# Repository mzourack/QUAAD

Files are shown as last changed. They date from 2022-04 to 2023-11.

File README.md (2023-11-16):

# QUAAD
quad 4-step Eurorack CV sequencer

current version:

PCB     V1.1

Panel   V1.1

**Features**

Demo: https://www.youtube.com/watch?v=YCnnyX1JADY

This module is basically 4 independent 4-step sequencers. Each of them features a CV output (0-5V), a clock divider (1-2-3-4-5-7-8-12-16-32 divisions) and a pattern setting.
There are 6 patterns available, each one unique, as there are no repeating 4-step sequences between the looped patterns. Patterns can be changed per-sequence via a dedicated knob or via CV, aswell as globally using the MSTR PTRN knob, which basically adds a CV offset to each of the pattern CV inputs. The full range of patterns can be accesed via the pot corresponding to pattern changes of individual sequencers, the MSTR PTRN knob or via 0-5V CV. The patterns are looped, so that when, for example, you are on the last of the 6 patterns and add some positive CV offset, you will go back to the first one and then further on...
The patterns are determined by this variable in the Arduino code:

    int patterns[] = {1, 2, 3, 4,
                      1, 2, 4, 3,
                      2, 4, 1, 3,
                      3, 4, 2, 1,
                      4, 2, 3, 1,
                      4, 3, 2, 1};

The sequencer can be reset via a gate or manually using a button.
With nothing patched into the clock input, the module is clocked internally, the tempo can be set via a potentiometer. The clock output outputs this internal clock when no external clock input is patched in, otherwise, the incoming clock signal is buffered through this output.

The module is 22HP, no 5V source required from the rack.



**Hardware**



Not much to say here, the build is fairly straight forward. It features SMD components, the passives are 0603. 

**Firmware**

Complete step-by-step flashing guide available in the pdf file in this repository.

The Atmega328P is running on Arduino code - this means an Arduino bootloader needs to be flashed before the .ino code. To flash it, you can use an arduino (uno or nano for example) and a couple of jumper wires. I recommend to flash the module disconnected from the rack - the 5V needed to run the chip can be provided via the ICSP header. I used a USBASP from aliexpress, it works great but was quite hard to get working, so I cannot recommend it. If you do go down the USBASP route, note that you need to place a jumper on the programmer that slows down the data transfer frequency - a factory fresh atmega328p won't be able to accept the bootloader at USBASP default speed.

Here's the pinout of the ICSP header used for flashing the chip:



Finally, TX and RX pins are available on the back of the module. These can theoretically be used to debug the module, and could prove useful for testing new firmware. However, clock div out C and D have to be disabled in such case.

**License**

Shield: [][cc-by]

This work is licensed under a
[Creative Commons Attribution 4.0 International License][cc-by].

[][cc-by]

[cc-by]: http://creativecommons.org/licenses/by/4.0/
[cc-by-image]: https://i.creativecommons.org/l/by/4.0/88x31.png
[cc-by-shield]: https://img.shields.io/badge/License-CC%20BY%204.0-lightgrey.svg

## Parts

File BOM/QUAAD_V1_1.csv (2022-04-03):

Id | Designator | Package | Quantity | Designation | Supplier and ref
1 | Ref** | logo_18 | 1 | Val**
2 | RV16,RV24,RV1,RV2,RV3,RV5,RV6,RV7,RV10,RV11,RV12,RV13,RV14,RV15,RV17,RV18,RV19,RV20,RV21,RV22,RV23,RV26,RV4,RV25,RV9,RV8 | Potentiometer_Alpha_RD901F-40-00D_Single_Vertical | 26 | B100K
3 | D20,D19,D10,D9,D4,D3,D2,D1 | D_SOD-123 | 8 | BAT42
4 | C6,C7,C8,C9,C10,C11,C12,C15,C16,C17,C18,C19,C25,C26,C27,C28,C29,C30,C31,C14 | C_0603_1608Metric | 20 | 100n
5 | R62,R61,R3,R4,R11,R12,R17,R18,R21,R22,R23,R24,R35,R36,R39,R40,R44,R45,R48,R49,R52,R53,R57,R58,R60 | R_0603_1608Metric | 25 | 1K
6 | J17 | PinHeader_1x02_P2.54mm_Vertical | 1 | Conn_01x02
7 | D35,D34,D33,D32,D31,D30,D29,D28,D27,D25,D24,D22,D21,D18,D17,D16,D15,D14,D13,D12,D11,D8,D7,D6,D5 | CENTERED_FLAT_LED | 25 | LED
8 | D26,D23 | D_SOD-123 | 2 | 1N4148W
9 | C1,C2,C3,C4,C5 | C_0603_1608Metric | 5 | 470n
10 | C13,C20 | CP_Elec_5x5.8 | 2 | 22u
11 | C21,C22 | C_0603_1608Metric | 2 | 18p
12 | C23,C24 | C_0603_1608Metric | 2 | 1u
13 | CON1 | IDC-Header_2x05_P2.54mm_Vertical | 1 | POWER
14 | D36,D37 | D_SOD-123F | 2 | SM4001
15 | J1,J2,J3,J4,J5,J7,J8,J9,J10,J11,J12,J13,J14,J15,J6 | Jack_3.5mm_QingPu_WQP-PJ398SM_Vertical | 15 | THONKICONN
16 | J16 | PinHeader_2x03_P2.54mm_Vertical | 1 | ICSP
17 | Q1,Q2 | SOT-23 | 2 | MMBT3904
18 | R1,R2,R7,R8,R15,R16,R25,R26,R29,R30,R37,R38 | R_0603_1608Metric | 12 | 68K
19 | R5,R6,R9,R10,R13,R14,R27,R28,R31,R32,R33,R34,R51,R59 | R_0603_1608Metric | 14 | 10K
20 | R19,R20,R41,R42,R43 | R_0603_1608Metric | 5 | 33K
21 | R46,R50 | R_0603_1608Metric | 2 | 100K
22 | R47 | R_0603_1608Metric | 1 | 220K
23 | R54,R55,R56 | R_0603_1608Metric | 3 | 1M
24 | U3,U4,U8,U9 | SOP-16_4.55x10.3mm_P1.27mm | 4 | CD4052B
25 | U12 | TQFP-32_7x7mm_P0.8mm | 1 | ATmega328P-AU
26 | Y1 | Crystal_SMD_HC49-SD | 1 | 16MHz
27 | SW1 | SW_PUSH_6mm | 1 | SW_DIP_x01
28 | U11 | SOT-223-3_TabPin2 | 1 | LM1117-5.0
29 | U1,U2,U5,U6,U10 | SOIC-14_3.9x8.7mm_P1.27mm | 5 | TL074
30 | U7 | SOIC-8_3.9x4.9mm_P1.27mm | 1 | TL072

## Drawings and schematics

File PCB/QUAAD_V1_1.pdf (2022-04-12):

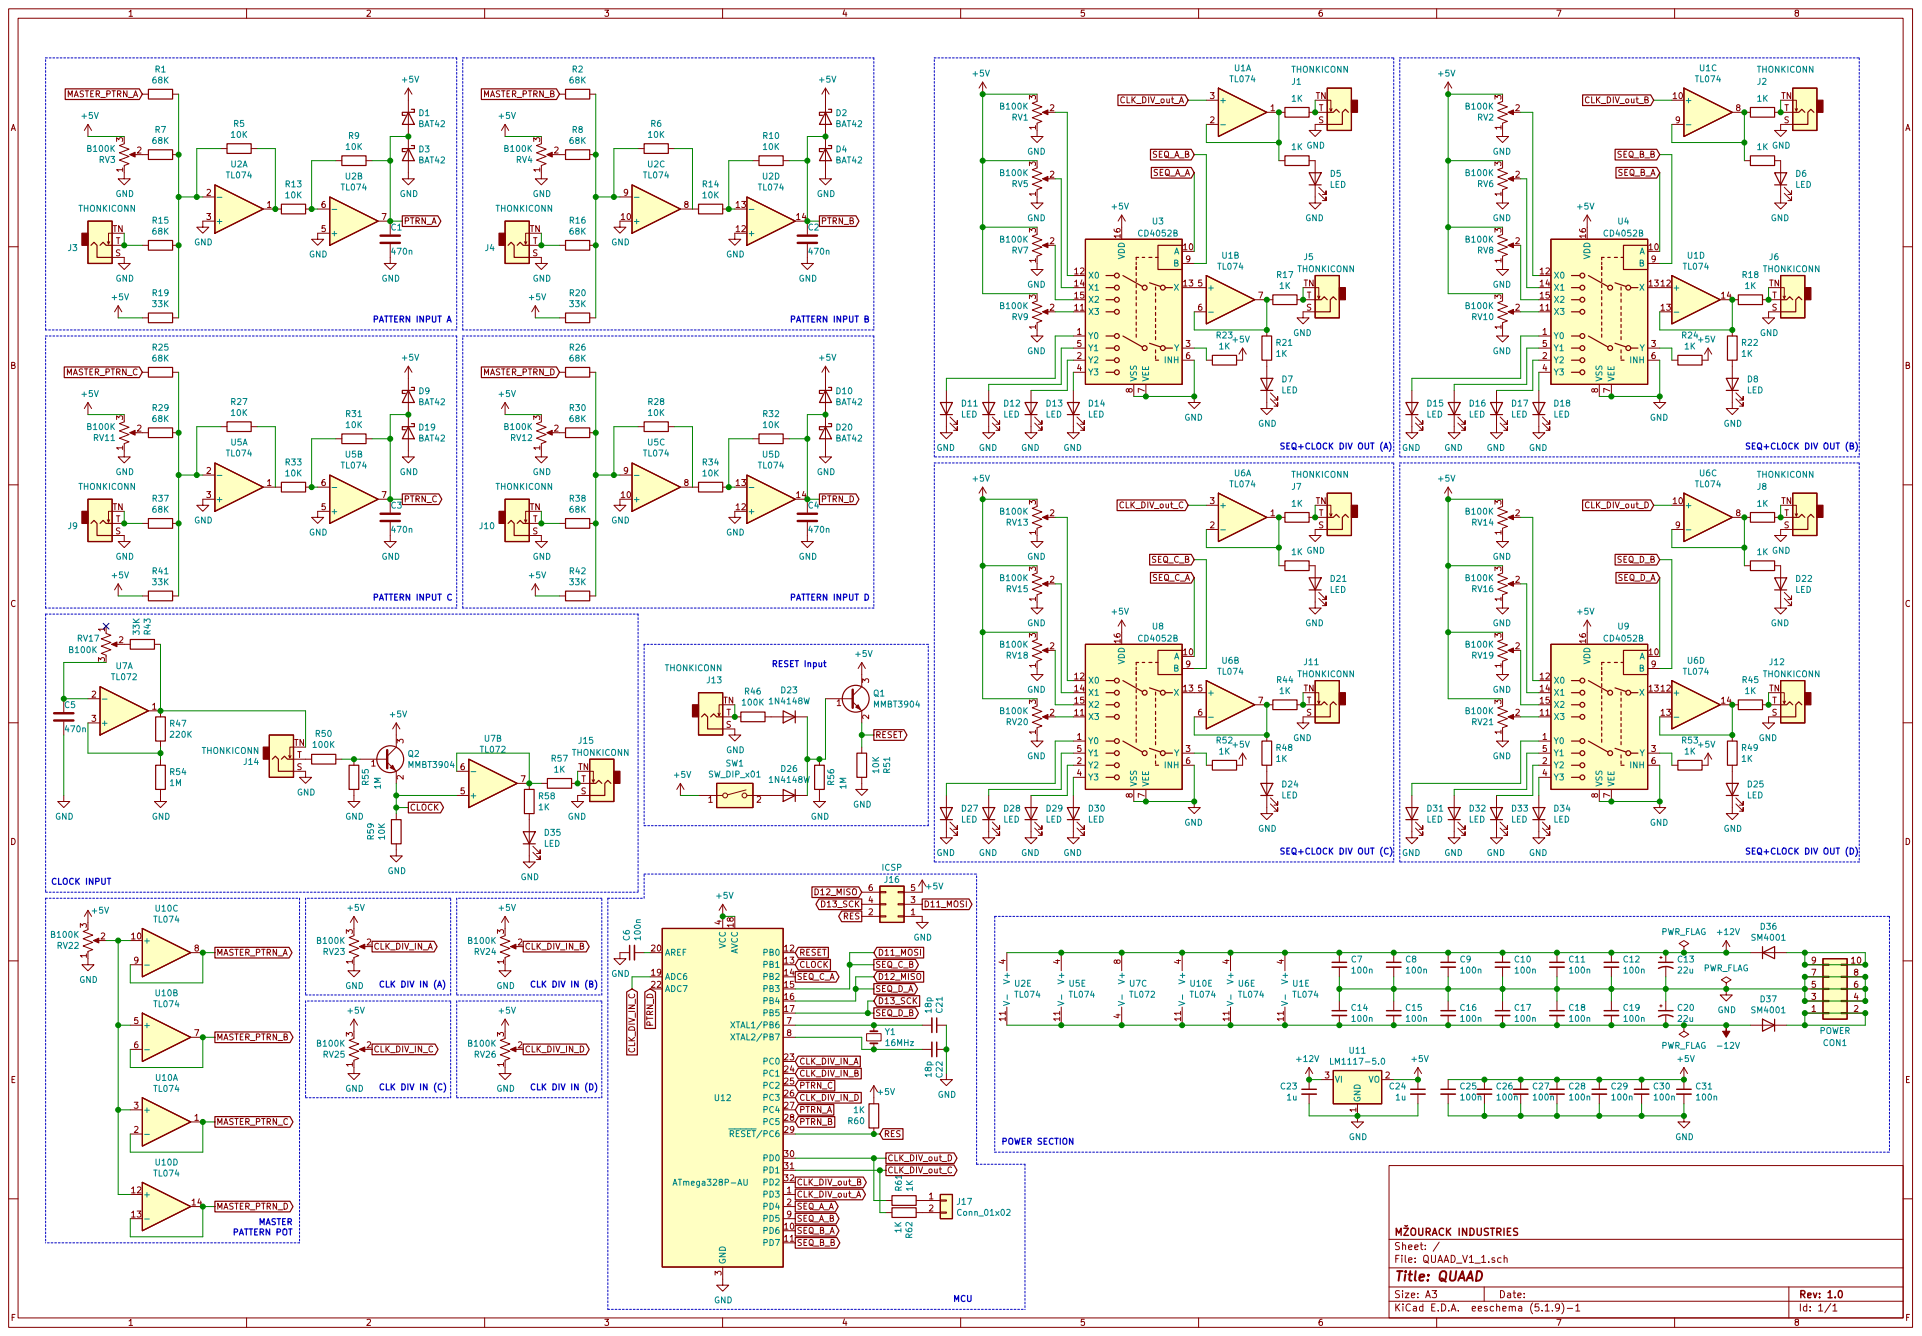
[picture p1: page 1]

SEQ+CLOCK DIV OUT (C)

2 | - 9 U10C 10 | 2 | 2 CLK DIV IN (B)

GND +5V 2 CLK DIV IN (C) | GND GND GND +5V 2 CLK DIV IN (D)

File: QUAAD_V1_1.sch Sheet: / MOURACK INDUSTRIES

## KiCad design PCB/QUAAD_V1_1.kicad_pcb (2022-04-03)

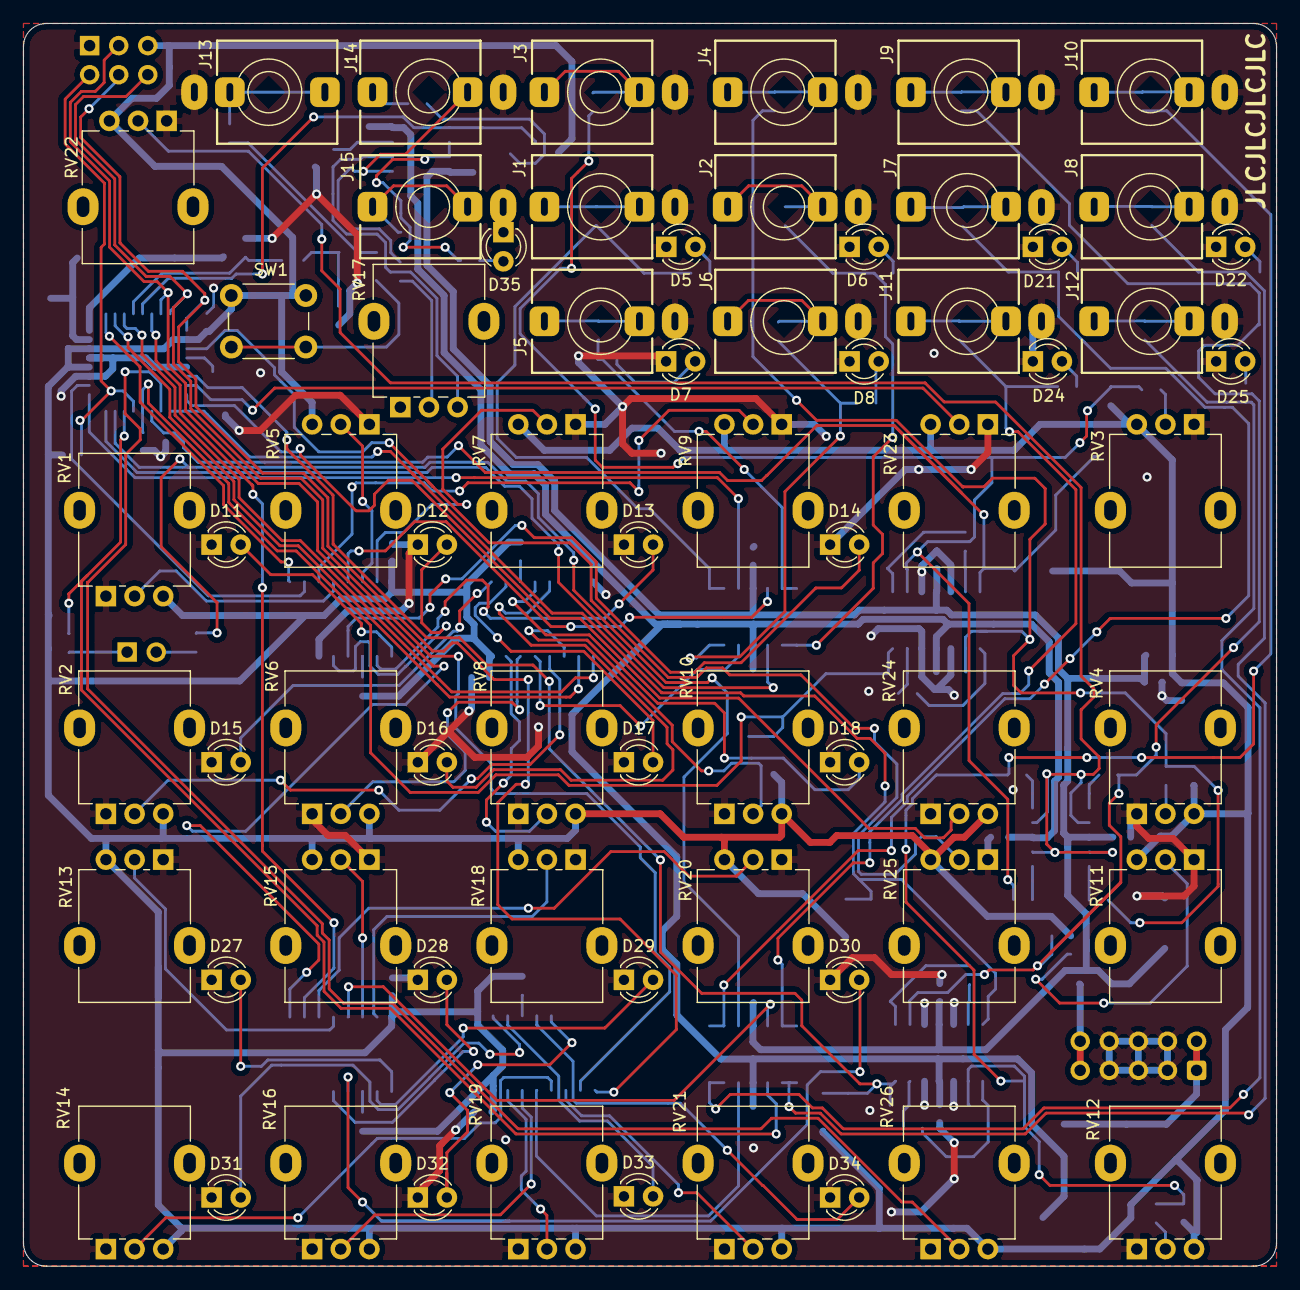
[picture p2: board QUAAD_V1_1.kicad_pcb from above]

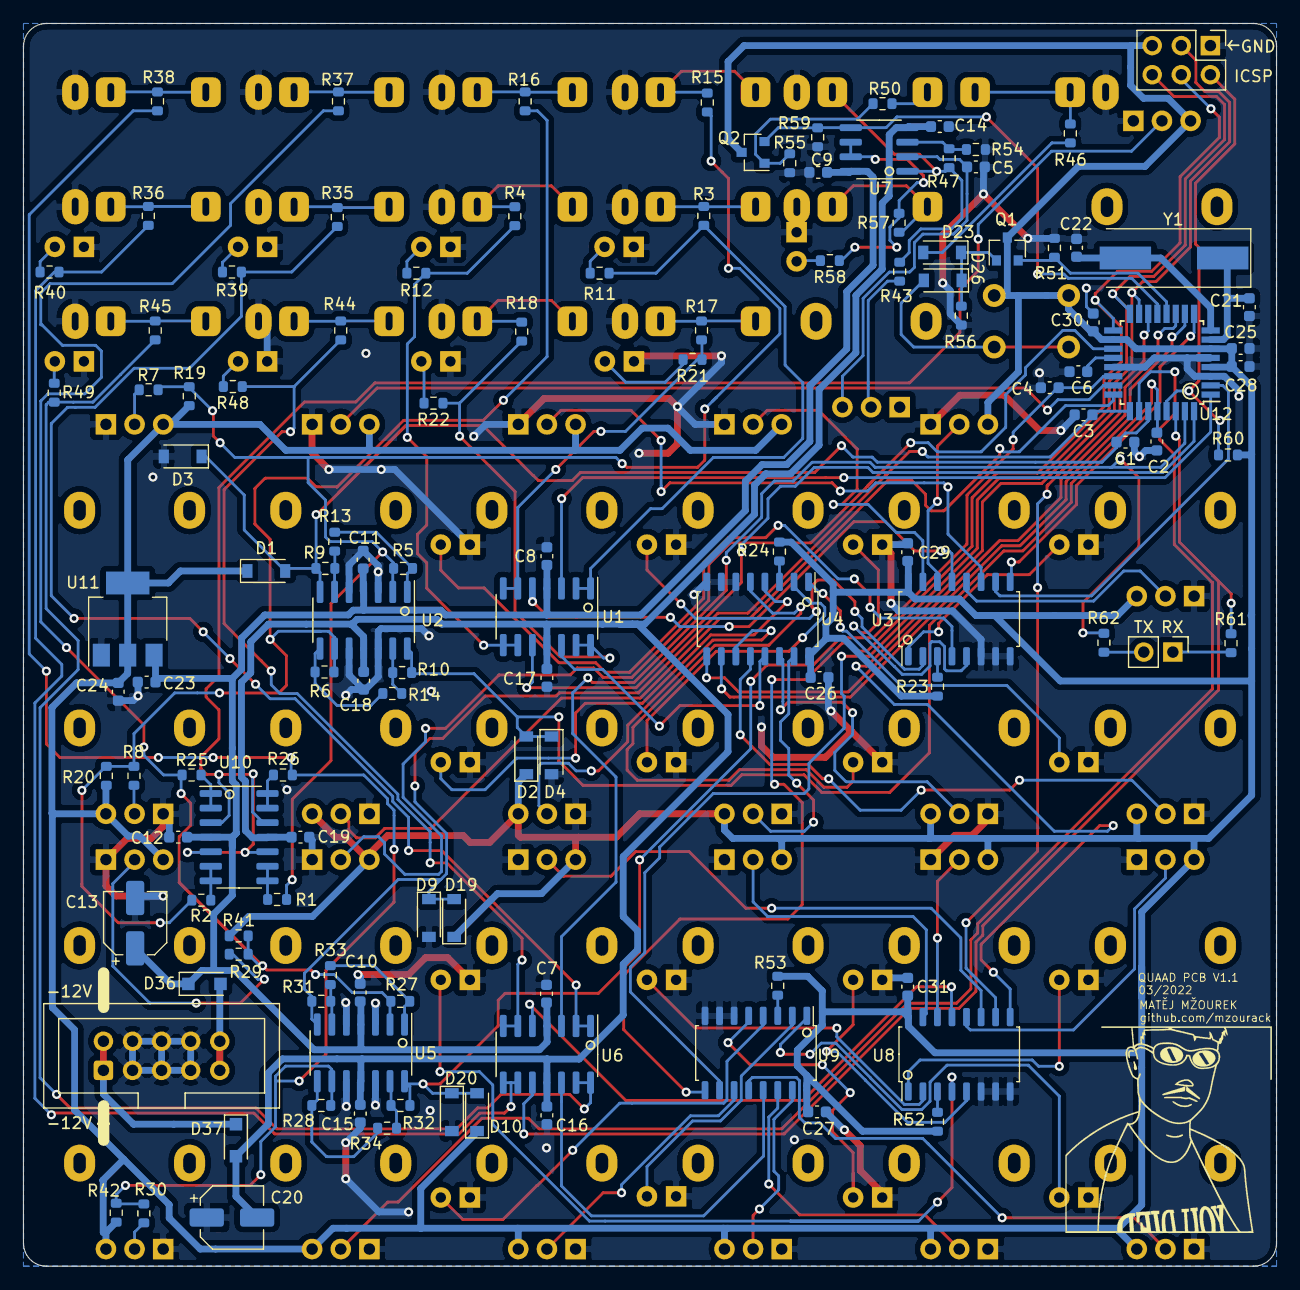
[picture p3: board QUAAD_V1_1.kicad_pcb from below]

Board: 2 copper layers, 109.4 x 108.5 mm, 191 parts (123 on the bottom side), 136 nets.

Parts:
C1, C2, C3, C4, C5: 470n; C_0603_1608Metric
C6, C7, C8, C9, C10, C11, C12, C14, C15, C16, C17, C18, C19, C25, C26, C27, C28, C29, C30, C31: 100n; C_0603_1608Metric
C13, C20: 22u; CP_Elec_5x5.8
C21, C22: 18p; C_0603_1608Metric
C23, C24: 1u; C_0603_1608Metric
CON1: POWER; IDC-Header_2x05_P2.54mm_Vertical
D1, D2, D3, D4, D9, D10, D19, D20: BAT42; D_SOD-123
D5, D6, D7, D8, D11, D12, D13, D14, D15, D16, D17, D18, D21, D22, D24, D25, D27, D28, D29, D30, D31, D32, D33, D34, D35: LED; CENTERED_FLAT_LED
D23, D26: 1N4148W; D_SOD-123
D36, D37: SM4001; D_SOD-123F
J1, J2, J3, J4, J5, J6, J7, J8, J9, J10, J11, J12, J13, J14, J15: THONKICONN; Jack_3.5mm_QingPu_WQP-PJ398SM_Vertical
J16: ICSP; PinHeader_2x03_P2.54mm_Vertical
J17: Conn_01x02; PinHeader_1x02_P2.54mm_Vertical
Q1, Q2: MMBT3904; SOT-23
R1, R2, R7, R8, R15, R16, R25, R26, R29, R30, R37, R38: 68K; R_0603_1608Metric
R3, R4, R11, R12, R17, R18, R21, R22, R23, R24, R35, R36, R39, R40, R44, R45, R48, R49, R52, R53, R57, R58, R60, R61, R62: 1K; R_0603_1608Metric
R5, R6, R9, R10, R13, R14, R27, R28, R31, R32, R33, R34, R51, R59: 10K; R_0603_1608Metric
R19, R20, R41, R42, R43: 33K; R_0603_1608Metric
R46, R50: 100K; R_0603_1608Metric
R47: 220K; R_0603_1608Metric
R54, R55, R56: 1M; R_0603_1608Metric
RV1, RV2, RV3, RV4, RV5, RV6, RV7, RV8, RV9, RV10, RV11, RV12, RV13, RV14, RV15, RV16, RV17, RV18, RV19, RV20, RV21, RV22, RV23, RV24, RV25, RV26: B100K; Potentiometer_Alpha_RD901F-40-00D_Single_Vertical
Ref**: Val**; logo_18
SW1: SW_DIP_x01; SW_PUSH_6mm
U1, U2, U5, U6, U10: TL074; SOIC-14_3.9x8.7mm_P1.27mm
U3, U4, U8, U9: CD4052B; SOP-16_4.55x10.3mm_P1.27mm
U7: TL072; SOIC-8_3.9x4.9mm_P1.27mm
U11: LM1117-5.0; SOT-223-3_TabPin2
U12: ATmega328P-AU; TQFP-32_7x7mm_P0.8mm
Y1: 16MHz; Crystal_SMD_HC49-SD

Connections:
+5V: C24.1, C25.1, C26.1, C27.1, C28.1, C29.1, C30.1, C31.1, D1.1, D2.1, D9.1, D10.1, J16.5, Q1.3, Q2.3, R19.2, R20.2, R23.1, R24.1, R41.2, R42.2, R52.1, R53.1, R60.2, RV1.3, RV2.3, RV3.3, RV4.3, RV5.3, RV6.3, RV7.3, RV8.3, RV9.3, RV10.3, RV11.3, RV12.3, RV13.3, RV14.3, RV15.3, RV16.3, RV18.3, RV19.3, RV20.3, RV21.3, RV22.3, RV23.3, RV24.3, RV25.3, RV26.3, SW1.1, U3.16, U4.16, U8.16, U9.16, U11.2, U12.4, U12.6, U12.18
+12V: C7.1, C8.1, C9.1, C10.1, C11.1, C12.1, C13.1, C23.1, D36.1, U1.4, U2.4, U5.4, U6.4, U7.8, U10.4, U11.3
-12V: C14.2, C15.2, C16.2, C17.2, C18.2, C19.2, C20.2, D37.2, U1.11, U2.11, U5.11, U6.11, U7.4, U10.11
CLK_DIV_IN_A: RV23.2, U12.23
CLK_DIV_IN_B: RV24.2, U12.24
CLK_DIV_IN_C: RV25.2, U12.19
CLK_DIV_IN_D: RV26.2, U12.26
CLK_DIV_out_A: U1.3, U12.1
CLK_DIV_out_B: U1.10, U12.32
CLK_DIV_out_C: R62.2, U6.3, U12.31
CLK_DIV_out_D: R61.1, U6.10, U12.30
CLOCK: Q2.2, R59.1, U7.5, U12.13
D11_MOSI: J16.3, U8.9, U12.15
D12_MISO: J16.6, U9.10, U12.16
D13_SCK: J16.4, U9.9, U12.17
GND: C1.2, C2.2, C3.2, C4.2, C5.2, C6.1, C7.2, C8.2, C9.2, C10.2, C11.2, C12.2, C13.2, C14.1, C15.1, C16.1, C17.1, C18.1, C19.1, C20.1, C21.1, C22.1, C23.2, C24.2, C25.2, C26.2, C27.2, C28.2, C29.2, C30.2, C31.2, CON1.3, CON1.4, CON1.5, CON1.6, CON1.7, CON1.8, D3.2, D4.2, D5.1, D6.1, D7.1, D8.1, D11.1, D12.1, D13.1, D14.1, D15.1, D16.1, D17.1, D18.1, D19.2, D20.2, D21.1, D22.1, D24.1, D25.1, D27.1, D28.1, D29.1, D30.1, D31.1, D32.1, D33.1, D34.1, D35.1, J1.S, J2.S, J3.S, J4.S, J5.S, J6.S, J7.S, J8.S, J9.S, J10.S, J11.S, J12.S, J13.S, J14.S, J15.S, J16.1, R51.2, R54.2, R55.2, R56.2, R59.2, RV1.1, RV2.1, RV3.1, RV4.1, RV5.1, RV6.1, RV7.1, RV8.1, RV9.1, RV10.1, RV11.1, RV12.1, RV13.1, RV14.1, RV15.1, RV16.1, RV18.1, RV19.1, RV20.1, RV21.1, RV22.1, RV23.1, RV24.1, RV25.1, RV26.1, U2.3, U2.5, U2.10, U2.12, U3.6, U3.7, U3.8, U4.6, U4.7, U4.8, U5.3, U5.5, U5.10, U5.12, U8.6, U8.7, U8.8, U9.6, U9.7, U9.8, U11.1, U12.3, U12.5, U12.21
MASTER_PTRN_A: R1.2, U10.8, U10.9
MASTER_PTRN_B: R2.2, U10.6, U10.7
MASTER_PTRN_C: R25.2, U10.1, U10.2
MASTER_PTRN_D: R26.2, U10.13, U10.14
unnamed: C5.1, RV17.3, U7.2
unnamed: C6.2, U12.20
unnamed: C21.2, U12.7, Y1.1
unnamed: C22.2, U12.8, Y1.2
unnamed: CON1.1, CON1.2, D37.1
unnamed: CON1.9, CON1.10, D36.2
unnamed: D5.2, R11.1
unnamed: D6.2, R12.1
unnamed: D7.2, R21.2
unnamed: D8.2, R22.2
unnamed: D11.2, U3.1
unnamed: D12.2, U3.5
unnamed: D13.2, U3.2
unnamed: D14.2, U3.4
unnamed: D15.2, U4.1
unnamed: D16.2, U4.5
unnamed: D17.2, U4.2
unnamed: D18.2, U4.4
unnamed: D21.2, R39.1
unnamed: D22.2, R40.1
unnamed: D23.1, D26.1, Q1.1, R56.1
unnamed: D23.2, R46.2
unnamed: D24.2, R48.2
unnamed: D25.2, R49.2
unnamed: D26.2, SW1.2
unnamed: D27.2, U8.1
unnamed: D28.2, U8.5
unnamed: D29.2, U8.2
unnamed: D30.2, U8.4
unnamed: D31.2, U9.1
unnamed: D32.2, U9.5
unnamed: D33.2, U9.2
unnamed: D34.2, U9.4
unnamed: D35.2, R58.2
unnamed: J1.T, J1.TN, R3.1
unnamed: J2.T, J2.TN, R4.1
unnamed: J3.T, J3.TN, R15.2
unnamed: J4.T, J4.TN, R16.2
unnamed: J5.T, J5.TN, R17.1
unnamed: J6.T, J6.TN, R18.1
unnamed: J7.T, J7.TN, R35.1
unnamed: J8.T, J8.TN, R36.1
unnamed: J9.T, J9.TN, R37.2
unnamed: J10.T, J10.TN, R38.2
unnamed: J11.T, J11.TN, R44.1
unnamed: J12.T, J12.TN, R45.1
unnamed: J13.T, J13.TN, R46.1
unnamed: J14.T, R50.1
unnamed: J14.TN, R43.1, R47.1, U7.1
unnamed: J15.T, J15.TN, R57.1
unnamed: J17.1, R61.2
unnamed: J17.2, R62.1
unnamed: Q2.1, R50.2, R55.1
unnamed: R1.1, R5.2, R7.1, R15.1, R19.1, U2.2
unnamed: R7.2, RV3.2
unnamed: R8.2, RV4.2
unnamed: R10.2, R14.1, U2.13
unnamed: R3.2, R11.2, U1.1, U1.2
unnamed: R4.2, R12.2, U1.8, U1.9
unnamed: R9.2, R13.1, U2.6
unnamed: R5.1, R13.2, U2.1
unnamed: R6.1, R14.2, U2.8
unnamed: R2.1, R6.2, R8.1, R16.1, R20.1, U2.9
unnamed: R17.2, R21.1, U1.6, U1.7
unnamed: R18.2, R22.1, U1.13, U1.14
unnamed: R23.2, U3.3
unnamed: R24.2, U4.3
unnamed: R25.1, R27.2, R29.1, R37.1, R41.1, U5.2
unnamed: R26.1, R28.2, R30.1, R38.1, R42.1, U5.9
unnamed: R27.1, R33.2, U5.1
unnamed: R28.1, R34.2, U5.8
unnamed: R29.2, RV11.2
unnamed: R30.2, RV12.2
unnamed: R31.2, R33.1, U5.6
unnamed: R32.2, R34.1, U5.13
unnamed: R35.2, R39.2, U6.1, U6.2
unnamed: R36.2, R40.2, U6.8, U6.9
unnamed: R43.2, RV17.2
unnamed: R44.2, R48.1, U6.6, U6.7
unnamed: R45.2, R49.1, U6.13, U6.14
unnamed: R47.2, R54.1, U7.3
unnamed: R52.2, U8.3
unnamed: R53.2, U9.3
unnamed: R57.2, R58.1, U7.6, U7.7
unnamed: RV1.2, U3.12
unnamed: RV2.2, U4.12
unnamed: RV5.2, U3.14
unnamed: RV6.2, U4.14
unnamed: RV7.2, U3.15
unnamed: RV8.2, U4.15
unnamed: RV9.2, U3.11
unnamed: RV10.2, U4.11
unnamed: RV13.2, U8.12
unnamed: RV14.2, U9.12
unnamed: RV15.2, U8.14
unnamed: RV16.2, U9.14
unnamed: RV18.2, U8.15
unnamed: RV19.2, U9.15
unnamed: RV20.2, U8.11
unnamed: RV21.2, U9.11
unnamed: RV22.2, U10.3, U10.5, U10.10, U10.12
unnamed: U1.5, U3.13
unnamed: U1.12, U4.13
unnamed: U6.5, U8.13
unnamed: U6.12, U9.13
PTRN_A: C1.1, D1.2, D3.1, R9.1, U2.7, U12.27
PTRN_B: C2.1, D2.2, D4.1, R10.1, U2.14, U12.28
PTRN_C: C3.1, D9.2, D19.1, R31.1, U5.7, U12.25
PTRN_D: C4.1, D10.2, D20.1, R32.1, U5.14, U12.22
RES: J16.2, R60.1, U12.29
RESET: Q1.2, R51.1, U12.12
SEQ_A_A: U3.10, U12.2
SEQ_A_B: U3.9, U12.9
SEQ_B_A: U4.10, U12.10
SEQ_B_B: U4.9, U12.11
SEQ_C_A: U8.10, U12.14

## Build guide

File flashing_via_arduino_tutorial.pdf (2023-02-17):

QUAAD flashing tutorial

This is a step-by-step guide for flashing the atmega328p chip on MŽOURACK – QUAAD.

1) Install Arduino IDE software on your computer (version 2.0.3 running on Windows 11 used for this guide) - https://www.arduino.cc/
2) Connect an Arduino board (Nano used here, UNO should work the same way) to your computer via USB.
3) In the Arduino IDE, go to File -> Examples -> 11.ArduinoISP -> ArduinoISP.
This script will turn your Arduino board into a programming tool for flashing the atmega328p on the QUAAD.

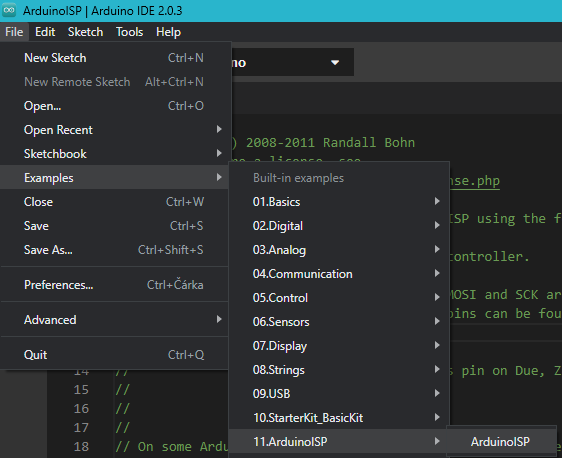
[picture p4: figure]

Go to Tools -> Port and select the port to which the Arduino board is connected. If you only have one Arduino board connected to your computer, you should only see one option.

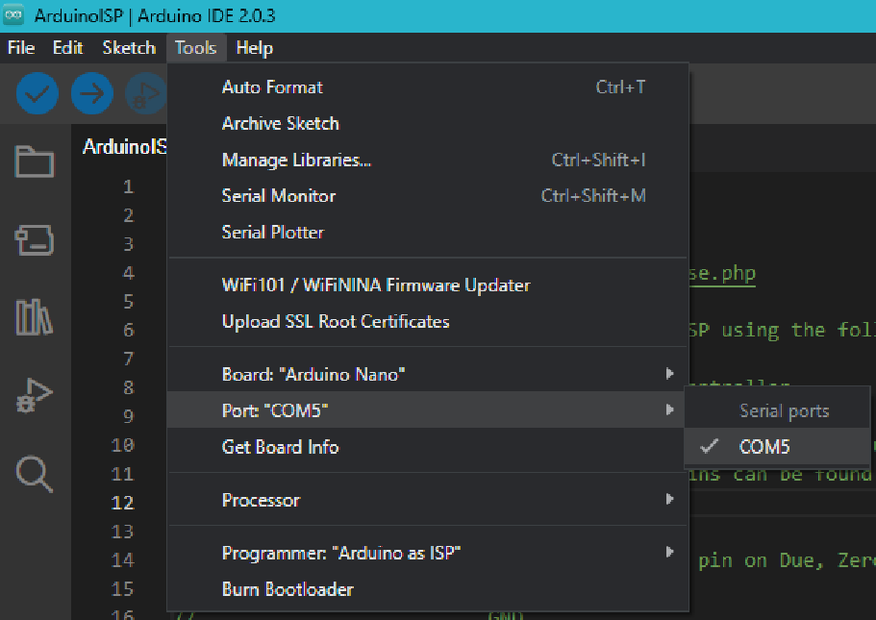
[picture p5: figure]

Go to Tools -> Board -> Arduino AVR Boards and select the Arduino board you are using. In this example, it is the Nano.

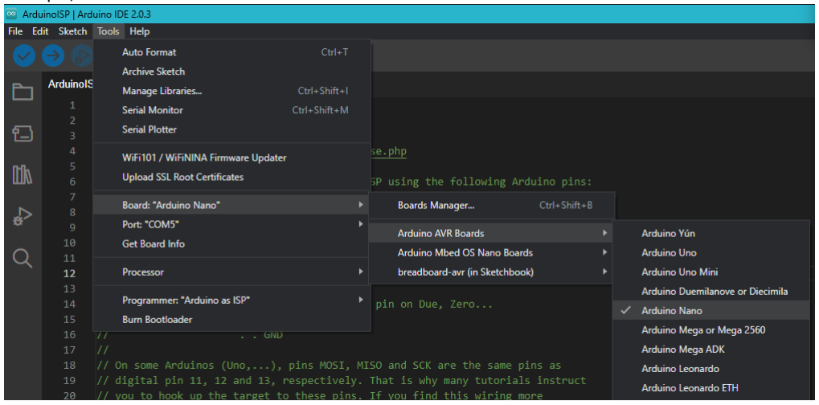
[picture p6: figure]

Now upload the ArduinoISP code to the Arduino board via Sketch -> Upload.

4) Unplug the Arduino board from your computer. Now connect the Arduino board to the 2x3 header on the QUAAD board. The module IS NOT connected to your eurorack power supply.
Below, you see the pinout of the header on the QUAAD board.
Connect the RES pin to the SS pin on your Arduino board (marked D10 on the Arduino Nano).

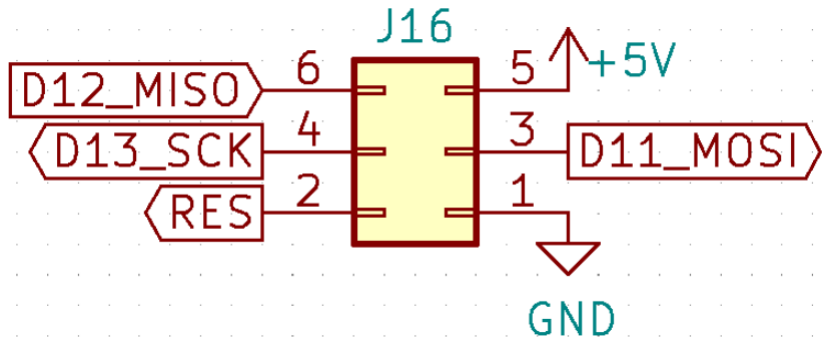
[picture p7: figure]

Connect the rest of the pins on the QUAAD 2x3 header to the same respective pins on the Arduino board. The Pinout is summarized in the table below.
QUAAD Pin | Arduino Pin | Arduino Nano pin name
GND | GND | GND
RES | SS | D10
MOSI | MOSI | D11
SCK | SCK | D13
+5V | 5V | 5V
MISO | MISO | D12
Below is an example of the connection.

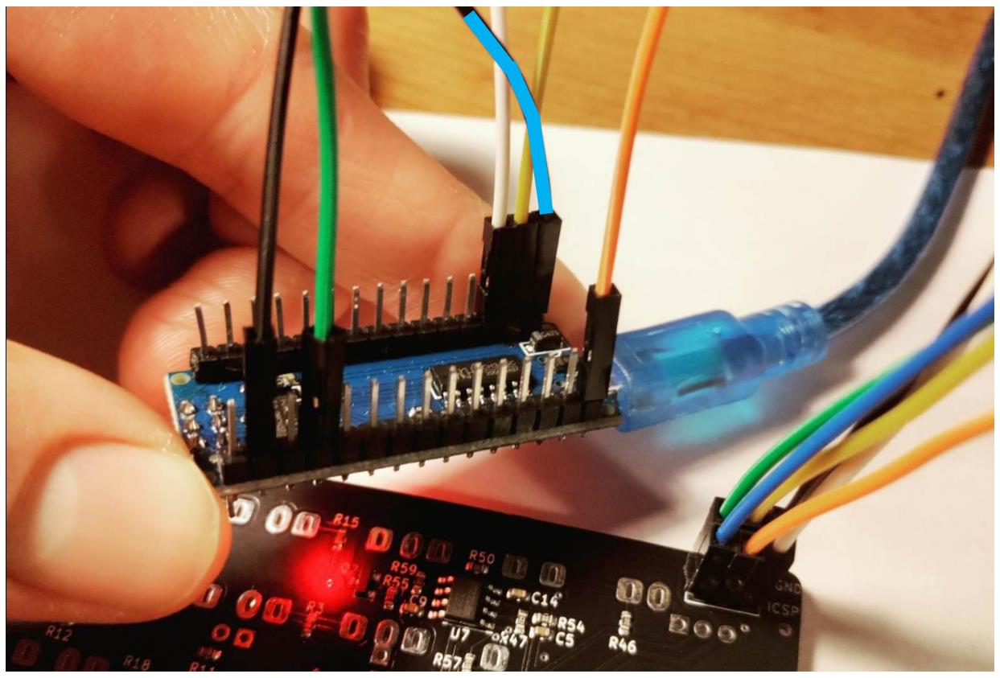
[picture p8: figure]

5) Connect the Arduino board back to your computer via USB.
6) Download the QUAAD firmware https://github.com/mzourack/QUAAD (it is an .ino file) and open it using Arduino IDE – File -> Open...
7) In Tools, set Programmer to „Arduino as ISP“. Burn the Arduino Bootloader to the Atmega328p on the QUAAD board by going to Tools -> Burn Bootloader. You should get a confirmation message after this is done – Done burning bootloader.

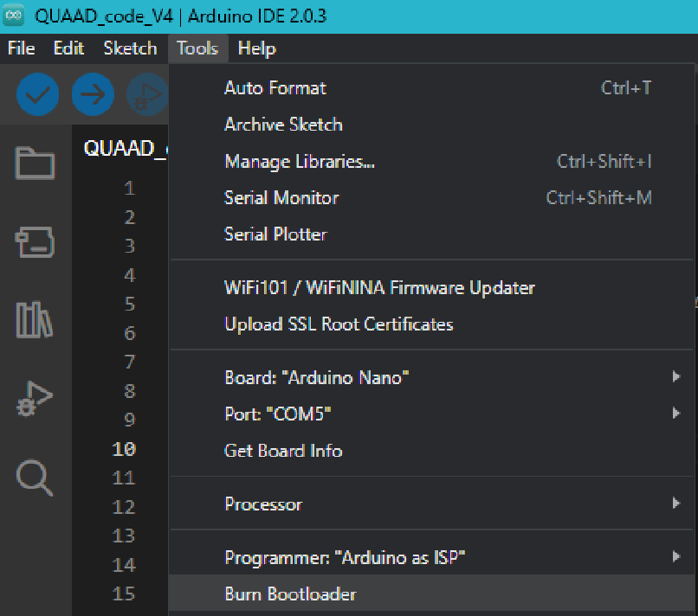
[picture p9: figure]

8) Finally, with the QUAAD .ino file still open, go to Sketch -> Upload Using Programmer. This should result in the Done uploading confirmation message.

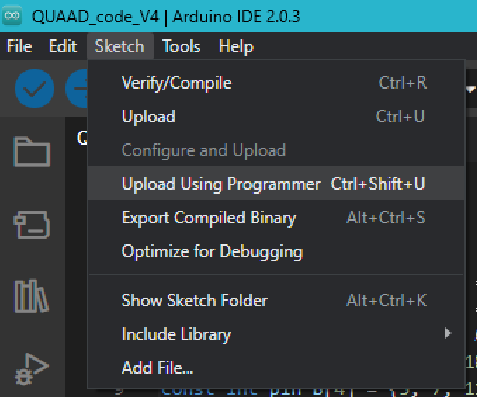
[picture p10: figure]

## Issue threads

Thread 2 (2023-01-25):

Traces below the pots

Yulquen, 2023-01-25:
Hi,

thanks for sharing your design. FYI I just noticed that there are many traces just below the pots, see below on the picture.

As the pots could me slighly moving and scratch the mask, it could create a shortcut.

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

Thx

mzourack, 2023-01-25:
Hey there,
really appreciate the feedback - sounds like a good point, never saw anyone bringing this up.
As the pots are supposed to be tightly attached to the panel with a nut, I don't see them being able to move at all, the module is really stiff.
Anyway, this is something I'll probably be watching out for from now on, I can see it being a problem in some cases.
Hope your build goes smooth!

Yulquen, 2023-01-25:
I remember one another build where they recommended to put Kapton tape below the pots because they had the issue once.

Closed 2023-01-26.

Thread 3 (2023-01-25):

Can we use 10k pots?

Yulquen, 2023-01-25:
I guess we can as they are used as voltage divider, but worth to check before soldering 25pots ;)
Thanks

mzourack, 2023-01-25:
Built some with 10k pots and it's no problem EXCEPT for the tempo pot, where it would change the tempo range.

Closed 2023-01-26.

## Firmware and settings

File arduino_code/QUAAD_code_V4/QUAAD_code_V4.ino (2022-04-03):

//// VARIABLES ////
// Pin addressing
const int pin_CLOCK = 9;
const int pin_RESET = 8;
const int pin_CLK_DIV_IN[4]  = {A0, A1, A6, A3}; //Analog pins
const int pin_CLK_DIV_OUT[4] = {3, 2, 1, 0}; //Digital pins
const int pin_PTRN[4] = {A4, A5, A2, A7};
const int pin_A[4] = {4, 6, 10, 12};
const int pin_B[4] = {5, 7, 11, 13};


// Reset input
bool wasReset = false;

// Clock input
int last_clock_state = 0;
int curr_clock_state = 0;
bool went_up   = false;
bool went_down = false;
int clockCount = 0;

// Clock divider
int divisions[] = {32, 16, 12, 8, 7, 5, 4, 3, 2, 1};
int mapped_div_ind = 1;
int clock_div_read = 0;
int division[4] = {1, 1, 1, 1};
int clock_div_mid[4] = {2000, 2000, 2000, 2000};

// Pattern reader
int pattern_read = 0;
int ptrn_size = 30;
int ptrn_offset = 309;
int ptrn_mid[4] = {2000, 2000, 2000, 2000};
int pattern[4] = {1, 1, 1, 1};
// Sequencer
int seq_step = 1;

void setup() {
analogReference(DEFAULT);
pinMode(pin_CLOCK,INPUT);
for (int i = 0; i <= 3; i++){
pinMode(pin_A[i],OUTPUT); pinMode(pin_B[i],OUTPUT); pinMode(pin_CLK_DIV_OUT[i],OUTPUT);
//pinMode(pin_PTRN[i],INPUT); pinMode(pin_CLK_DIV_IN[i],INPUT);
clock_div_read = analogRead(pin_CLK_DIV_IN[i]);
    mapped_div_ind   = constrain(map(clock_div_read,0,922,0,9),0,9);
    division[i]      = divisions[mapped_div_ind];
    clock_div_mid[i] = 51+(1024/10)*mapped_div_ind;
}
}

void loop() {
// Reset input
if (digitalRead(pin_RESET) == HIGH){
  if (wasReset == false){
    clockCount = 0;
    wasReset = true;}}
else {wasReset = false;}
  
// Clock input
curr_clock_state = digitalRead(pin_CLOCK);
if      (curr_clock_state == 1 & last_clock_state == 0){went_up   = true;
                                                        if(clockCount<3360){clockCount++;} //3360 can be divided by the numbers in divisions[]
                                                        else               {clockCount=1;}}
else if (curr_clock_state == 0 & last_clock_state == 1){went_down = true;}
else                                                   {went_up = false; went_down = false;}
last_clock_state = curr_clock_state;


// Clock Divider, Sequencer
if (went_up){
  for (int i = 0; i <= 3; i++) { 
    
    if ((clockCount+division[i]-1) % division[i] == 0){
    digitalWrite(pin_CLK_DIV_OUT[i],HIGH);
      seq_step = (((clockCount-1)/division[i])%4)+1;
      patternDriver(pattern[i],seq_step,pin_A[i],pin_B[i]);
    }
  }
}

if (went_down){
  for (int i = 0; i <= 3; i++){
    digitalWrite(pin_CLK_DIV_OUT[i],LOW);
        // Pattern reader
    pattern_read = analogRead(pin_PTRN[i])+ptrn_size/2;
    
    if (abs(pattern_read-ptrn_mid[i])>20){
      // -5:0 V
    if      (pattern_read >= 129 & pattern_read < 309) {pattern[i] = map(pattern_read,129,279,1,6); ptrn_mid[i] = ptrn_offset -6*ptrn_size + ptrn_size/2 + (pattern[i]-1)*ptrn_size;}
     // 0:5 V
    else if (pattern_read >= 309 & pattern_read < 489) {pattern[i] = map(pattern_read,309,459,1,6); ptrn_mid[i] = ptrn_offset +0*ptrn_size + ptrn_size/2 + (pattern[i]-1)*ptrn_size;}
     // 5:10 V
    else if (pattern_read >= 489 & pattern_read < 669) {pattern[i] = map(pattern_read,489,639,1,6); ptrn_mid[i] = ptrn_offset +6*ptrn_size + ptrn_size/2 + (pattern[i]-1)*ptrn_size;}
     // 10:15V
    else if (pattern_read >= 669 & pattern_read < 849) {pattern[i] = map(pattern_read,669,819,1,6); ptrn_mid[i] = ptrn_offset+12*ptrn_size + ptrn_size/2 + (pattern[i]-1)*ptrn_size;}
                                          }
       // Clock divider reader
    clock_div_read = analogRead(pin_CLK_DIV_IN[i]);
    if (abs(clock_div_read-clock_div_mid[i])>54){
    mapped_div_ind   = constrain(map(clock_div_read,0,922,0,9),0,9);
    division[i]      = divisions[mapped_div_ind];
    clock_div_mid[i] = 51+(1024/10)*mapped_div_ind;}
    
    }}
  
}

void patternDriver(int pattern, int seq_step, int pinA, int pinB){
    int patterns[] = {1, 2, 3, 4,
                      1, 2, 4, 3,
                      2, 4, 1, 3,
                      3, 4, 2, 1,
                      4, 2, 3, 1,
                      4, 3, 2, 1};
    int step_states[] = {LOW,  LOW,   // step 1 - B, A
                         LOW,  HIGH,  // step 2 - B, A
                         HIGH, LOW,   // step 3 - B, A
                         HIGH, HIGH}; // step 4 - B, A
                         
  digitalWrite(pinA, step_states[2*(patterns[4*(pattern-1)+seq_step-1]-1)+1]);   
  digitalWrite(pinB, step_states[2*(patterns[4*(pattern-1)+seq_step-1]-1)  ]);
}

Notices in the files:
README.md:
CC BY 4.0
